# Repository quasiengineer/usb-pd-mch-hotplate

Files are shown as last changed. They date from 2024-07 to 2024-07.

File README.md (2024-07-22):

# USB-powered hot plate

Video about this project:
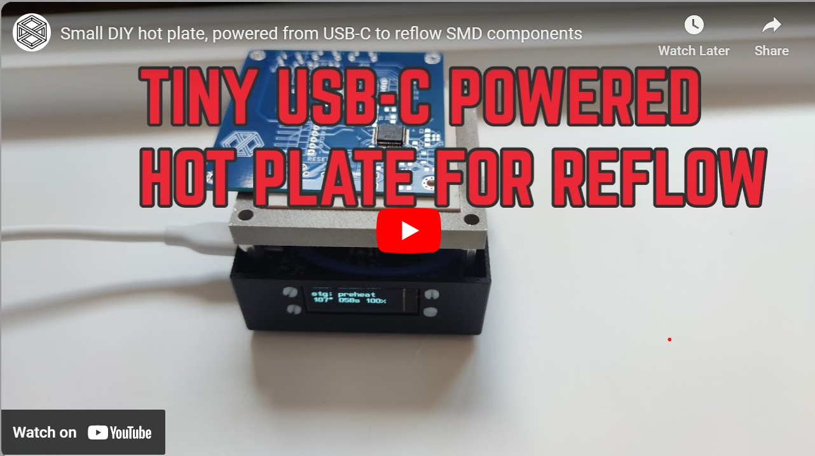
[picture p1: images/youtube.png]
Video about this project (https://www.youtube.com/watch?v=0ewrXzEZL8w)


## Board

Schematics in [pdf format](./pcb/usb-pd-mch-hotplate.pdf)

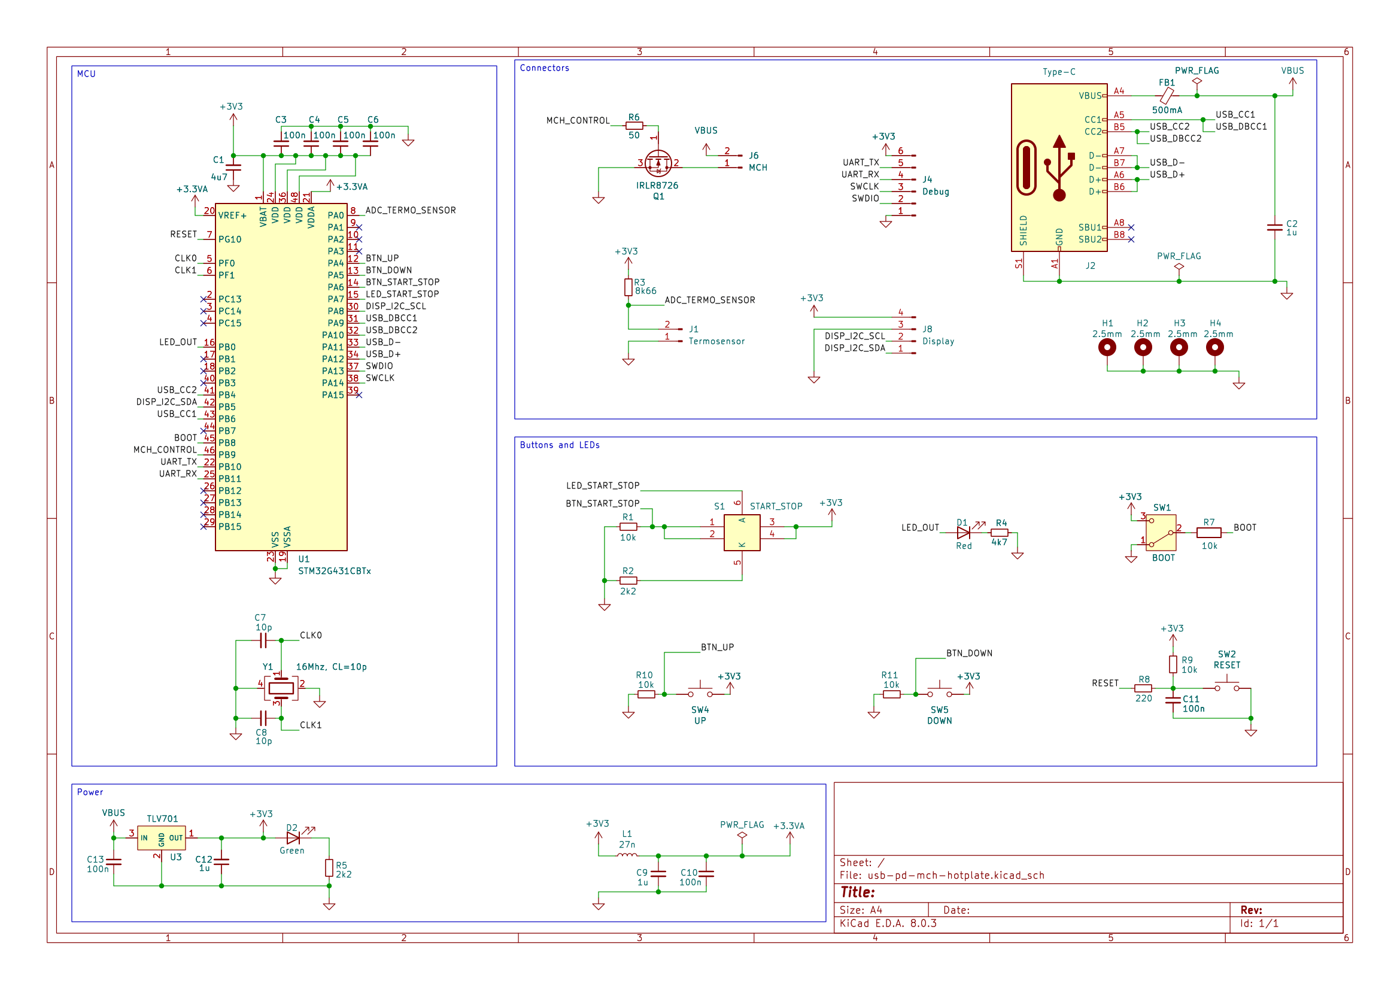
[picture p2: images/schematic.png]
schematic


Archive with gerber files and drill locations could be found [here](./pcb/manufacturing/manufacturing.zip)

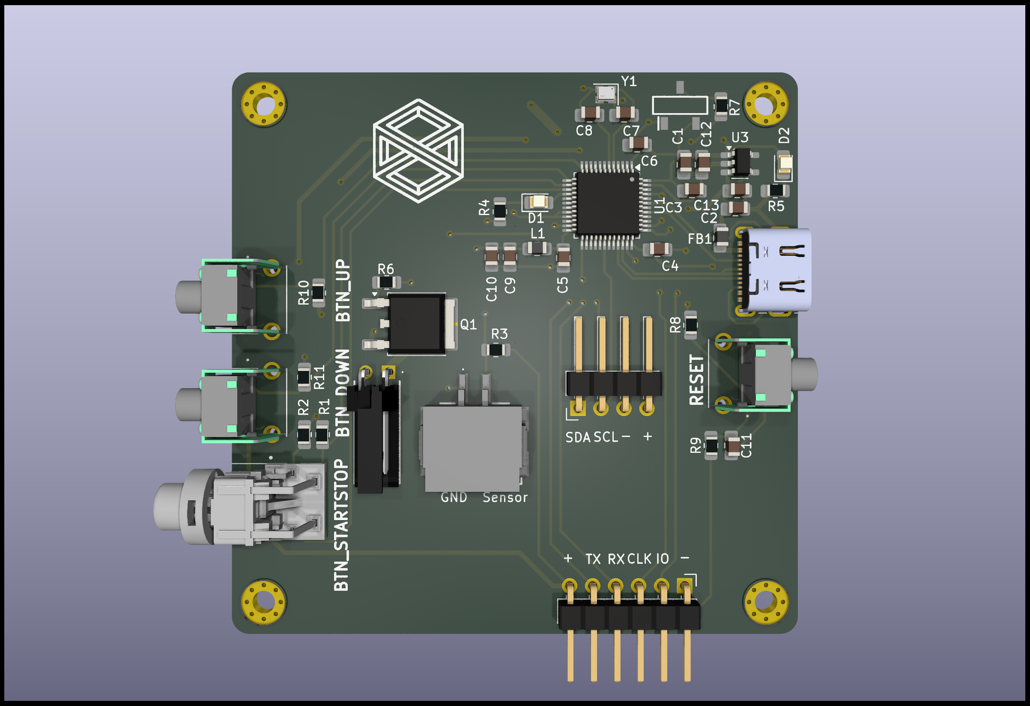
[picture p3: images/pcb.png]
pcb


Bill of material in [CSV format](./pcb/usb-pd-mch-hotplate.csv)

|Reference |Value |Mouser Part Number  |Qty|DNP|
|---|---|---|---|---|
|C1 |4u7 |187-CL21A475KPFNNNF |1  | |
|C2 |1u |187-CL21B105MBFNNNE |1  | |
|C3,C4,C5,C6,C10,C11,C13|100n |187-CL21B104KACNNND |7  | |
|C7,C8 |10p |603-CC805JRNPO9BN100|2  | |
|C9,C12 |1u |187-CL21B105KPFNNNE |2  | |
|D1 |Red |710-150080RS75000 |1  | |
|D2 |Green |710-150080GS75000 |1  | |
|FB1 |500mA |652-MH2029-301Y |1  | |
|J1 |Termosensor  |305-234832 |1  | |
|J2 |Type-C |656-DX07S016JA1R1500|1  | |
|J4 |Debug |649-1012937990604BLF|1  | |
|J6 |MCH |710-66100211722 |1  | |
|J8 |Display |649-10027011-404HLF |1  | |
|L1 |27n |652-CE201210-27NJ |1  | |
|Q1 |IRLR8726 |942-IRLR8726TRPBF |1  | |
|R1,R7,R9,R10,R11 |10k |603-RC0805FR-1010KL |5  | |
|R2,R5 |2k2 |603-RC0805FR-072K2L |2  | |
|R3 |8k66 |603-AC0805JR-073K3L |1  | |
|R4 |4k7 |603-RC0805FR-074K7P |1  | |
|R6 |50 |603-AC0805FR-07100RL|1  | |
|R8 |220 |603-RT0805FRE07220RL|1  | |
|S1 |START_STOP |612-TL1250F180GQRCLR|1  | |
|SW1 |BOOT |611-TDD01H0SB1R |1  | |
|SW2 |RESET |611-PTS645VH312 |1  | |
|SW4 |UP |611-PTS645VL582 |1  | |
|SW5 |DOWN |611-PTS645VL582 |1  | |
|U1 |STM32G431CBTx| 511-STM32G431CBT6  |1  | |
|U3 |TLV701 |595-TLV70133DBVRM3  |1  | |
|Y1 |16Mhz, CL=10p|81-XRCGB16M000FXN02R|1  | |

## Assembly

### Chassis

Step file for [board case](./chassis/PCB chassis.STEP)
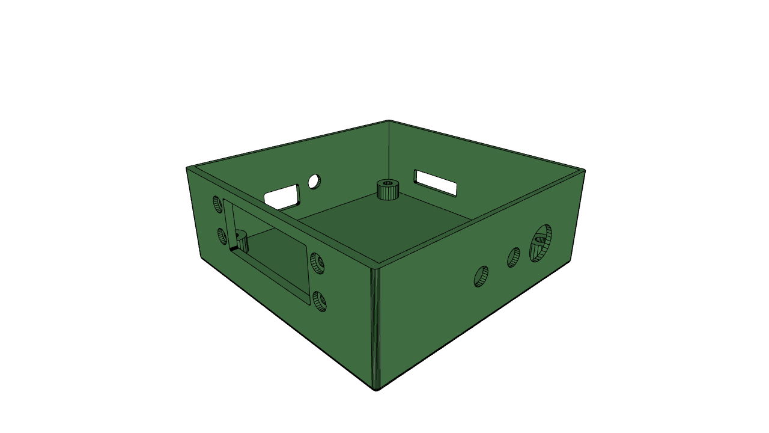
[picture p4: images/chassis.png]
chassis


Step file for [MCH holder](./chassis/MCH holder.STEP). Please note that it's better to adjust model for exact dimensions of MCH plate (plus some tolerance).
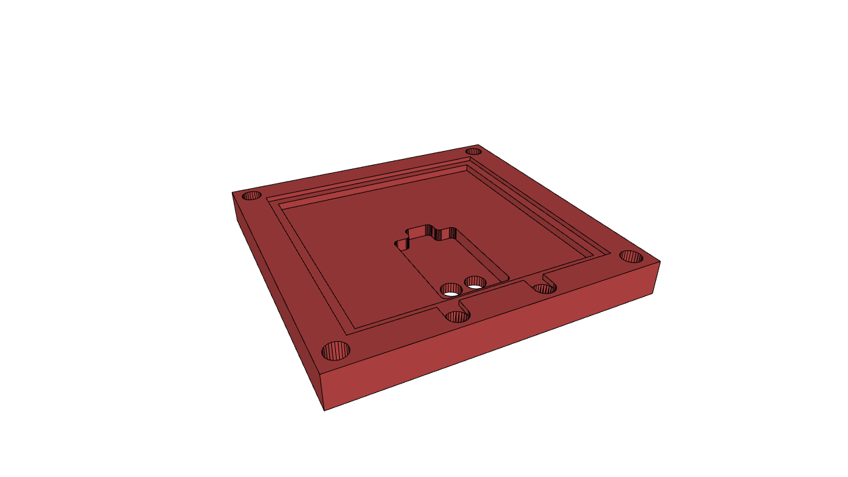
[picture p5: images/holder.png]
holder


### Hardware and extra parts

- MCH itself, 50x50x2mm, up to 24V, 150W
- steel washers, M2x5, 0.2mm thick, 8 pcs
- ceramic fiber paper
- brass inserts, M2xL4xOD3, 4 pcs
- steel standoffs, M2xL25, 4 pcs
- bolts for MCH holder mount, M2xL6xOD4, 4pcs
- NTC 100k thermistor, 	871-B57703M1104A002
- display, DFRobot DFR0647
- bolts for display mount, 144-04M020040HN, 4pcs
- nuts for display mount, 144-50M020040F004, 4pcs
- thermosensor connector, 305-364198
- thermosensor connector terminals, 305-464766 2pcs
- MCH element connector, 710-661002151922
- display connectors, 649-65039-033ELF, 2pcs
- display connector terminals, 649-47217-000LF, 8pcs
- kapton tape
- high temperature silicone sealant, K2 B205N

### Assembly steps

1. Install heat set inserts into PCB chassis
2. Place PCB inside chassis
3. Put washers from ceramic fiber paper at the mounting holes
4. Put steel washers above ceramic fiber paper washers
5. Screw standoffs to chassis mounting holes
6. Install display to the display slot by using 4 bolts and 4 nuts
7. Connect display to the board by using 4-pin cable
8. Glue thermo sensor to the MCH element
9. Better isolate MCH wires to avoid electrical contact with MCH holder
10. Place MCH plate into MCH holder and route wires from thermo sensor and MCH element itself through corresponding holes
11. Crimp connectors to thermo sensor and MCH element wires
12. Connect thermo sensor and MCH element to the female connectors on the board
13. Put steel washers to the upper part of standoffs 
14. Put washers from ceramic fiber paper above steel washers
15. Place MCH holder to standoffs and screw it

## Firmware

There is compiled [hex file](./firmware/bin/usb-pd-mch-hotplate.hex) in repository, that could be flashed to PCB.

Make sure that `BOOT` switch lever shifted in direction of logo and connect the board via USB and use stm32 programming software. I am using stm32programmer.

## Software

Make sure that `BOOT` switch lever shifted in direction to near board edge and connect the board via USB to USB PD 3.0 compatible power supply that can output at least 100W of power. 

Green LED should be lighting and red LED should be flashing.

Display should show initial menu with the list of programs.

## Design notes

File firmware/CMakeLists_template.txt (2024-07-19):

#${templateWarning}
set(CMAKE_SYSTEM_NAME Generic)
set(CMAKE_SYSTEM_VERSION 1)
${cmakeRequiredVersion}
# specify cross-compilers and tools
set(CMAKE_C_COMPILER arm-none-eabi-gcc)
set(CMAKE_CXX_COMPILER arm-none-eabi-g++)
set(CMAKE_ASM_COMPILER  arm-none-eabi-gcc)
set(CMAKE_AR arm-none-eabi-ar)
set(CMAKE_OBJCOPY arm-none-eabi-objcopy)
set(CMAKE_OBJDUMP arm-none-eabi-objdump)
set(SIZE arm-none-eabi-size)
set(CMAKE_TRY_COMPILE_TARGET_TYPE STATIC_LIBRARY)

# project settings
project(${projectName} C CXX ASM)
set(CMAKE_CXX_STANDARD 17)
set(CMAKE_C_STANDARD 11)

#Uncomment for hardware floating point
#add_compile_definitions(ARM_MATH_CM4;ARM_MATH_MATRIX_CHECK;ARM_MATH_ROUNDING)
#add_compile_options(-mfloat-abi=hard -mfpu=fpv4-sp-d16)
#add_link_options(-mfloat-abi=hard -mfpu=fpv4-sp-d16)

#Uncomment for software floating point
#add_compile_options(-mfloat-abi=soft)

add_compile_options(-mcpu=${mcpu} -mthumb -mthumb-interwork)
add_compile_options(-ffunction-sections -fdata-sections -fno-common -fmessage-length=0)

# uncomment to mitigate c++17 absolute addresses warnings
#set(CMAKE_CXX_FLAGS "$${CMAKE_CXX_FLAGS} -Wno-register")

# Enable assembler files preprocessing
add_compile_options($<$<COMPILE_LANGUAGE:ASM>:-x$<SEMICOLON>assembler-with-cpp>)

if ("$${CMAKE_BUILD_TYPE}" STREQUAL "Release")
    message(STATUS "Maximum optimization for speed")
    add_compile_options(-Ofast)
elseif ("$${CMAKE_BUILD_TYPE}" STREQUAL "RelWithDebInfo")
    message(STATUS "Maximum optimization for speed, debug info included")
    add_compile_options(-Ofast -g)
elseif ("$${CMAKE_BUILD_TYPE}" STREQUAL "MinSizeRel")
    message(STATUS "Maximum optimization for size")
    add_compile_options(-Os)
else ()
    message(STATUS "Minimal optimization, debug info included")
    add_compile_options(-Og -g)
endif ()

include_directories(${includes} App App/modules)

add_definitions(${defines})

file(GLOB_RECURSE SOURCES ${sources} "App/*.*")

set(LINKER_SCRIPT $${CMAKE_SOURCE_DIR}/${linkerScript})

add_link_options(-Wl,-gc-sections,--print-memory-usage,-Map=$${PROJECT_BINARY_DIR}/$${PROJECT_NAME}.map)
add_link_options(-mcpu=${mcpu} -mthumb -mthumb-interwork)
add_link_options(-T $${LINKER_SCRIPT})

add_executable($${PROJECT_NAME}.elf $${SOURCES} $${LINKER_SCRIPT})

set(HEX_FILE $${PROJECT_BINARY_DIR}/$${PROJECT_NAME}.hex)
set(BIN_FILE $${PROJECT_BINARY_DIR}/$${PROJECT_NAME}.bin)

add_custom_command(TARGET $${PROJECT_NAME}.elf POST_BUILD
        COMMAND $${CMAKE_OBJCOPY} -Oihex $<TARGET_FILE:$${PROJECT_NAME}.elf> $${HEX_FILE}
        COMMAND $${CMAKE_OBJCOPY} -Obinary $<TARGET_FILE:$${PROJECT_NAME}.elf> $${BIN_FILE}
        COMMENT "Building $${HEX_FILE}
Building $${BIN_FILE}")

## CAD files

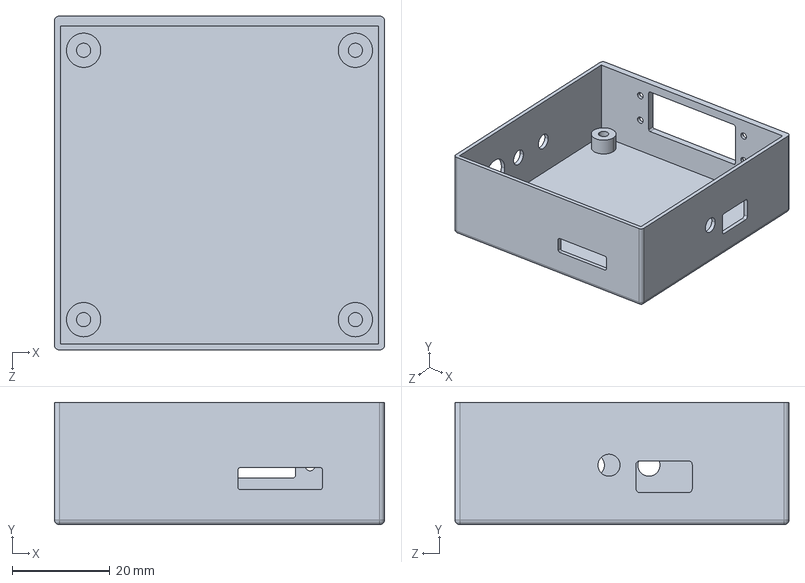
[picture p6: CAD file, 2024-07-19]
chassis/PCB chassis.STEP
67.4 x 25.0 x 68.2 mm

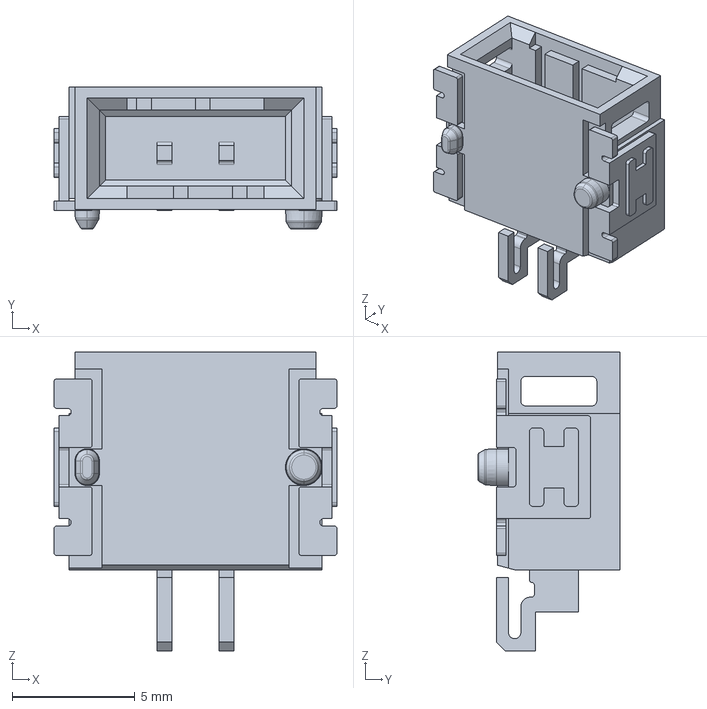
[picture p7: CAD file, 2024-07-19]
pcb/components/3d/c-234832-e-1-3d.stp
11.5 x 5.80 x 12.2 mm

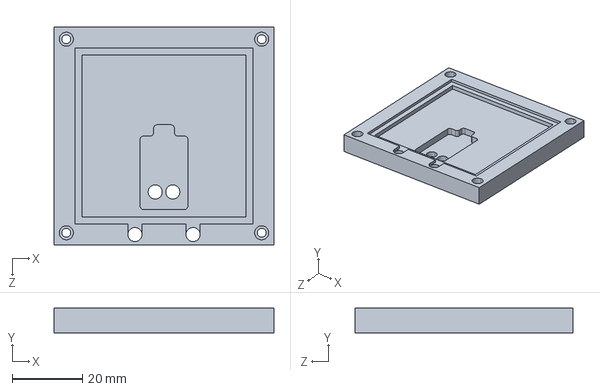
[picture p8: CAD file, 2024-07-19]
chassis/MCH holder.STEP
62.5 x 7.00 x 62.0 mm

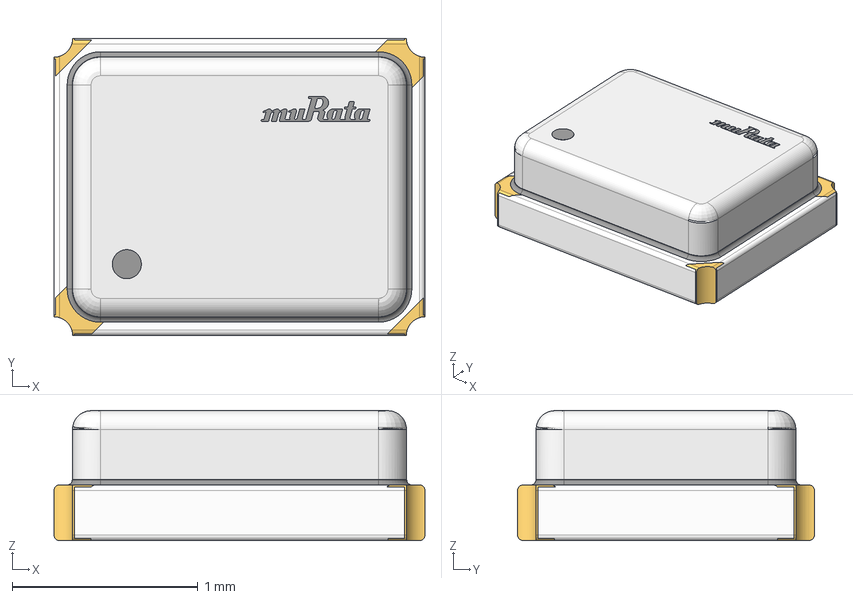
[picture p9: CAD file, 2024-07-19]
pcb/components/3d/XRCGB16M000FXN02R0.stp
2.00 x 1.60 x 0.702 mm

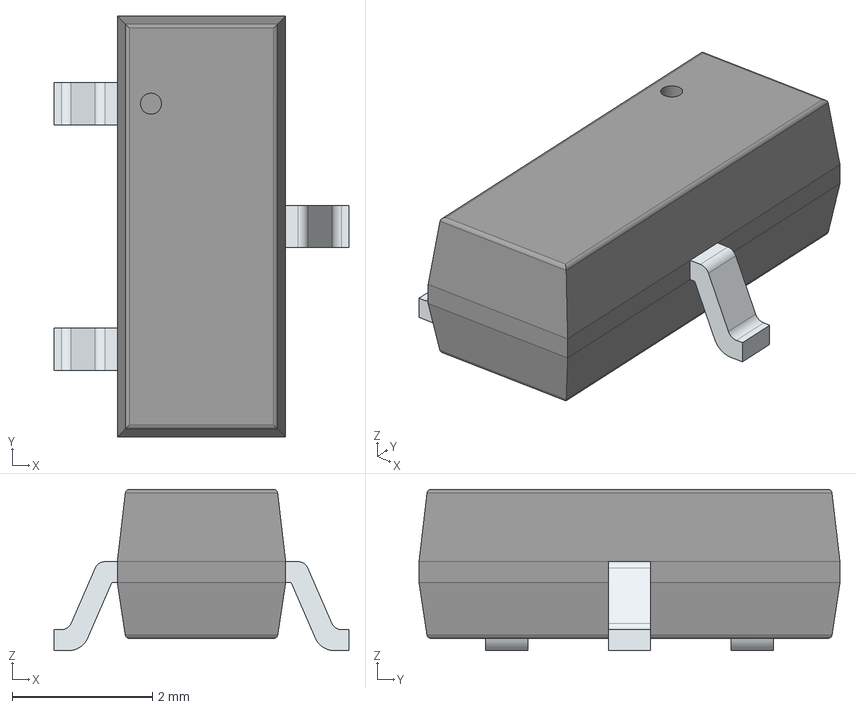
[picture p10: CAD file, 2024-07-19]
pcb/components/3d/TDD01H0SB1R.stp
4.20 x 6.00 x 2.30 mm
PinsArrayL
FilletPinR

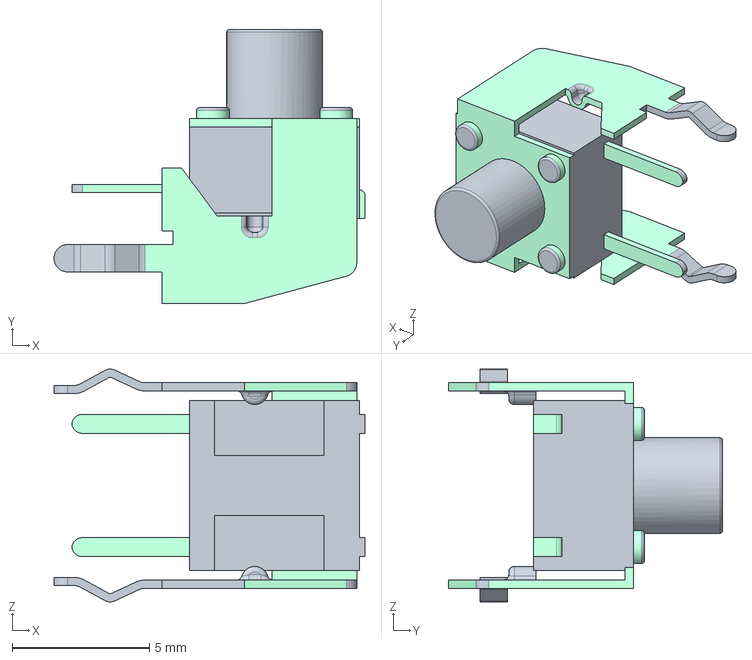
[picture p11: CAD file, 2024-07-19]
pcb/components/3d/PTS645VL58-2LFS.stp
11.4 x 10.0 x 8.50 mm

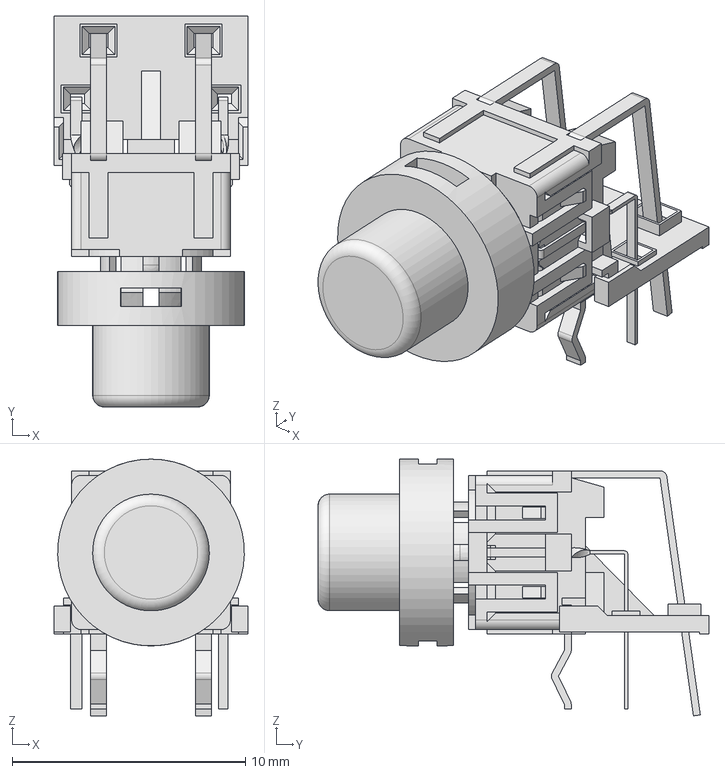
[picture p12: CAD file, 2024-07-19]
pcb/components/3d/TL1250F180GQRCLR.stp
8.30 x 16.8 x 11.0 mm

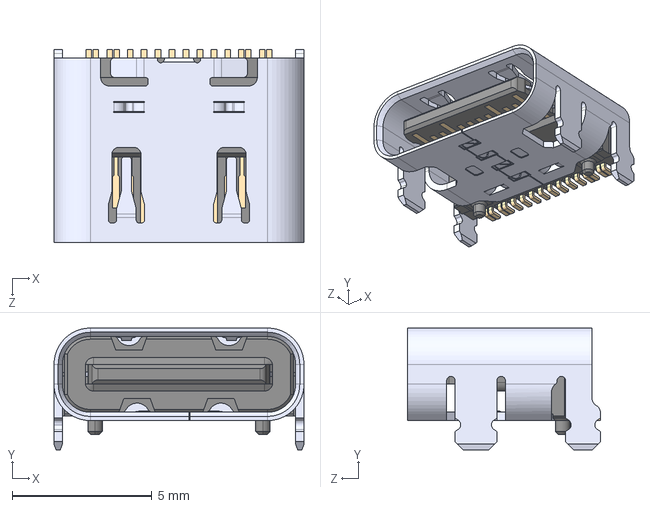
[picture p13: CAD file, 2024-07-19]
pcb/components/3d/DX07S016JA1R1500.stp
8.94 x 4.36 x 6.90 mm

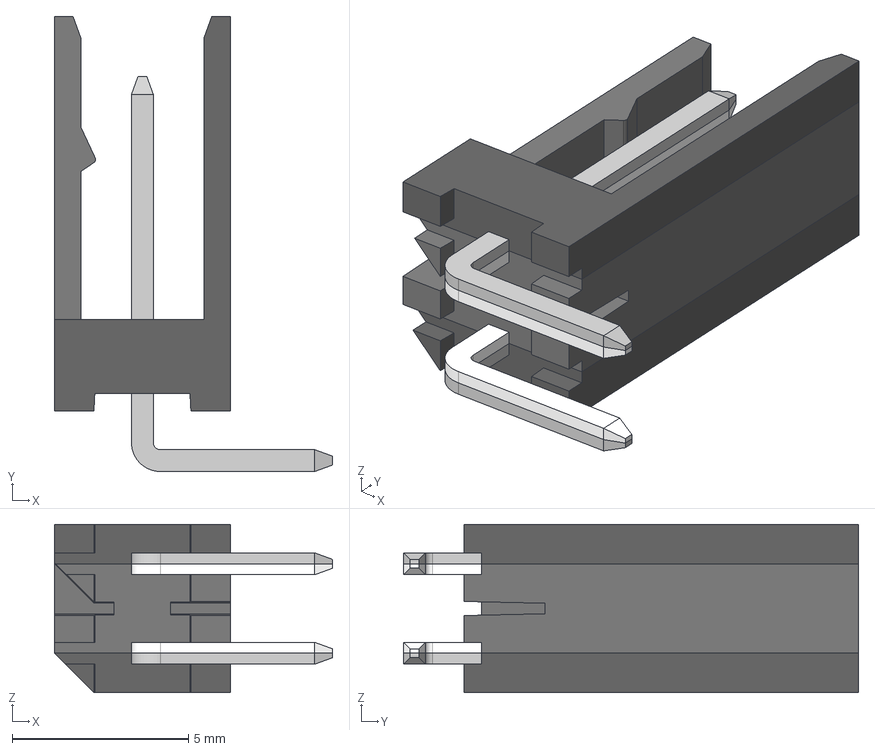
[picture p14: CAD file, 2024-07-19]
pcb/components/3d/66100211722 (rev1).stp
7.90 x 12.9 x 4.78 mm
6610xx11722_02_06_DX
6610xx11722_02_06_SX

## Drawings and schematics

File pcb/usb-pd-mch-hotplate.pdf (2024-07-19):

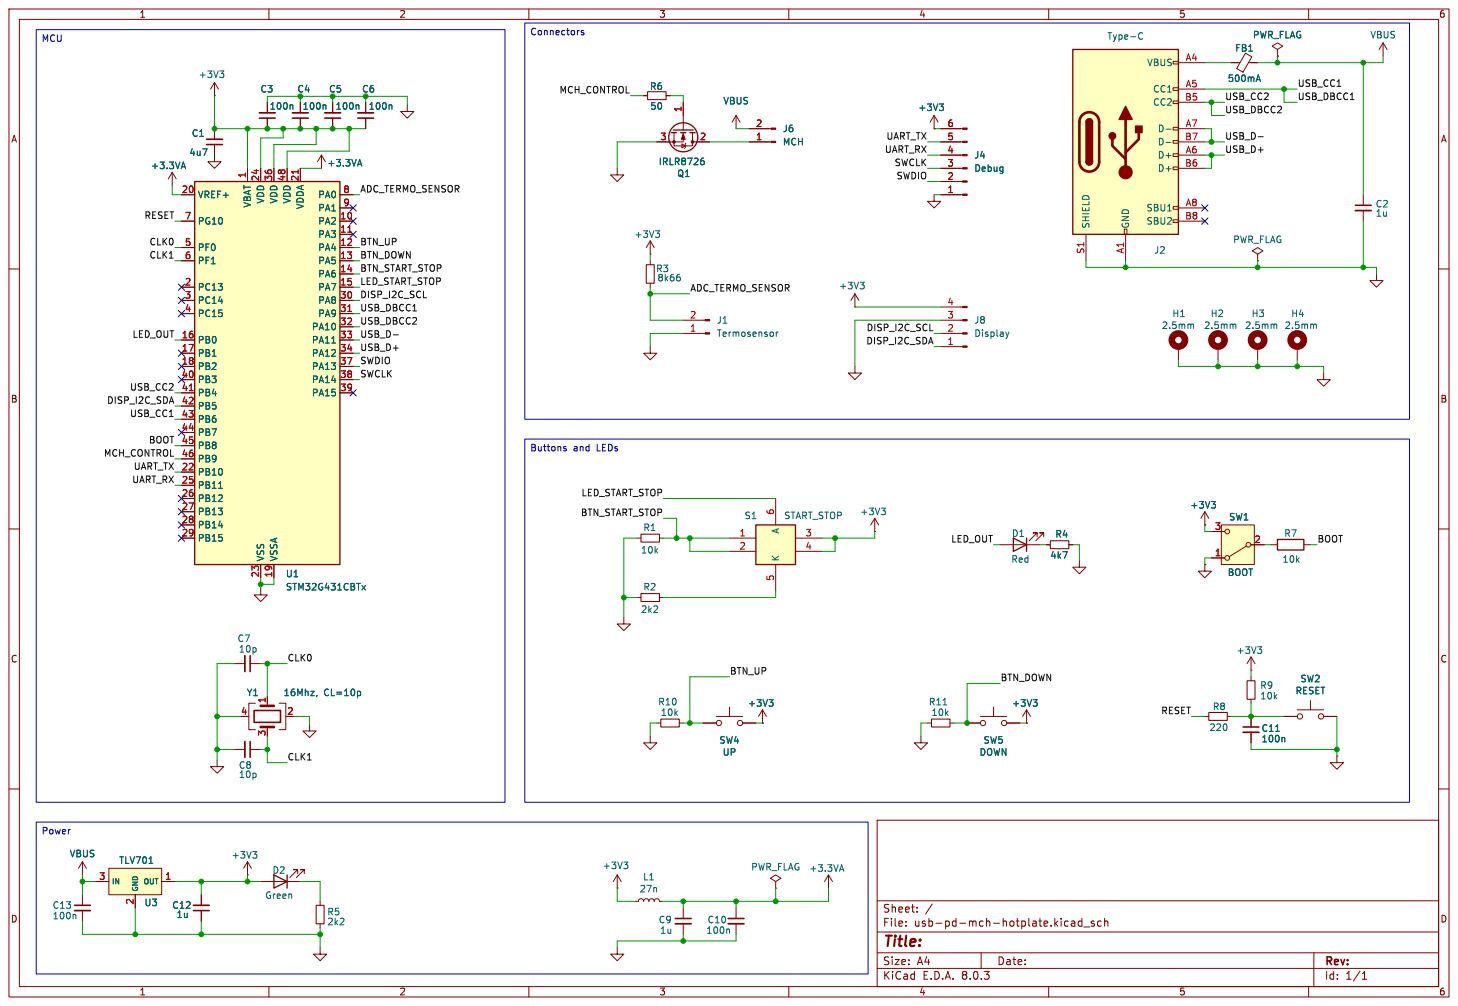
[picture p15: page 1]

1 PA2 10 PA3 11 PA4 12 PA5 13 PA6 14 PA7 15 PB0 16 PB1 17 PB2 18 VSSA 19 PC13 2 VREF+ 20 VDDA 21 PB10 22 VSS 23 VDD 24 PB11 25 PB12 26 PB13 27 PB14 28 PB15 29 PC14 3 PA8 30 PA9 31 PA10 32 PA11 33 PA12 34 VDD 36 PA13 37 PA14 38 PA15 39 PC15 4 PB3 40 PB4 41 PB5 42 PB6 43 PB7 44 PB8 45 PB9 46 VDD 48 PF0 5 PF1 6 PG10 7 PA0 8 PA1 9 U1STM32G431CBTx

1 PA2 10 PA3 11 PA4 12 PA5 13 PA6 14 PA7 15 PB0 16 PB1 17 PB2 18 VSSA 19 PC13 2 VREF+ 20 VDDA 21 PB10 22 VSS 23 VDD 24 PB11 25 PB12 26 PB13 27 PB14 28 PB15 29 PC14 3 PA8 30 PA9 31 PA10 32 PA11 33 PA12 34 VDD 36 PA13 37 PA14 38 PA15 39 PC15 4 PB3 40 PB4 41 PB5 42 PB6 43 PB7 44 PB8 45 PB9 46 VDD 48 PF0 5 PF1 6 PG10 7 PA0 8 PA1 9 Y1 16Mhz, CL=10p

Id: 1/1 Title: File: usb-pd-mch-hotplate.kicad_sch Sheet: / R1

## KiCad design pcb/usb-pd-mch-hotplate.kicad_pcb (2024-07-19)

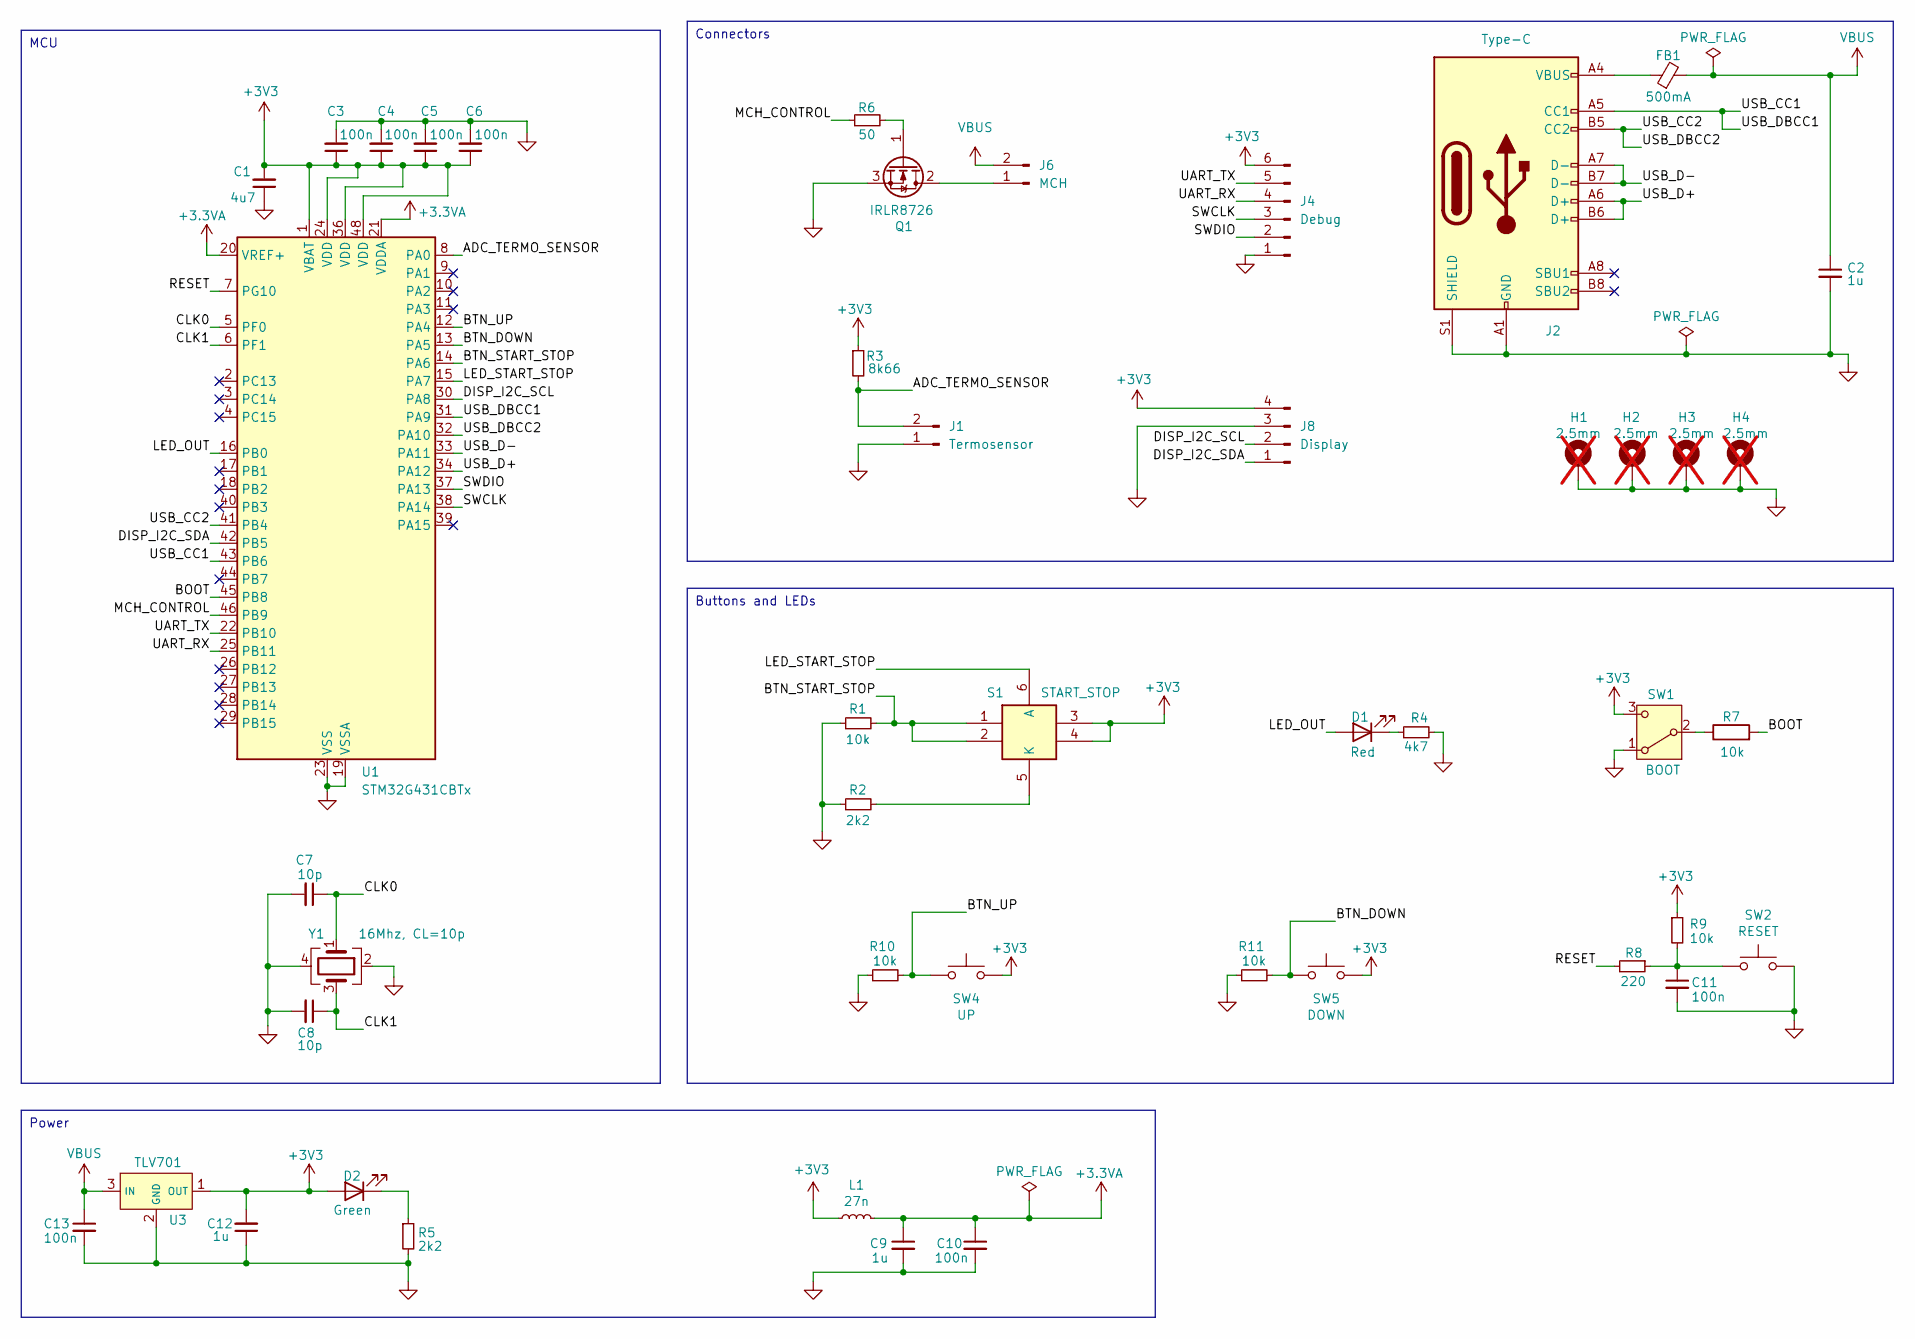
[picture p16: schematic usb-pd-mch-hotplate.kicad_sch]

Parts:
C1: 4u7; C_0805_2012Metric_Pad1.18x1.45mm_HandSolder; Mouser Part Number 187-CL21A475KPFNNNF
C2: 1u; C_0805_2012Metric_Pad1.18x1.45mm_HandSolder; Mouser Part Number 187-CL21B105MBFNNNE
C3, C4, C5, C6, C10, C11, C13: 100n; C_0805_2012Metric_Pad1.18x1.45mm_HandSolder; Mouser Part Number 187-CL21B104KACNNND
C7, C8: 10p; C_0805_2012Metric_Pad1.18x1.45mm_HandSolder; Mouser Part Number 603-CC805JRNPO9BN100
C9, C12: 1u; C_0805_2012Metric_Pad1.18x1.45mm_HandSolder; Mouser Part Number 187-CL21B105KPFNNNE
D1: Red; LED_0805_2012Metric_Pad1.15x1.40mm_HandSolder; Mouser Part Number 710-150080RS75000
D2: Green; LED_0805_2012Metric_Pad1.15x1.40mm_HandSolder; Mouser Part Number 710-150080GS75000
FB1: 500mA; L_0805_2012Metric_Pad1.15x1.40mm_HandSolder; Mouser Part Number 652-MH2029-301Y
H1, H2, H3, H4: 2.5mm; MountingHole_2.5mm_Pad_Via; not fitted
J1: Termosensor; 234832E; Mouser Part Number 305-234832
J2: Type-C; USB_C_Receptacle_JAE_DX07S016JA1R1500; Mouser Part Number 656-DX07S016JA1R1500
J4: Debug; PinHeader_1x06_P2.54mm_Horizontal; Mouser Part Number 649-1012937990604BLF
J6: MCH; Conn_66100211722; Mouser Part Number 710-66100211722
J8: Display; PinHeader_1x04_P2.54mm_Horizontal; Mouser Part Number 649-10027011-404HLF
L1: 27n; L_0805_2012Metric_Pad1.15x1.40mm_HandSolder; Mouser Part Number 652-CE201210-27NJ
Q1: IRLR8726; TO-252-2; Mouser Part Number 942-IRLR8726TRPBF
R1, R7, R9, R10, R11: 10k; R_0805_2012Metric_Pad1.20x1.40mm_HandSolder; Mouser Part Number 603-RC0805FR-1010KL
R2, R5: 2k2; R_0805_2012Metric_Pad1.20x1.40mm_HandSolder; Mouser Part Number 603-RC0805FR-072K2L
R3: 8k66; R_0805_2012Metric_Pad1.20x1.40mm_HandSolder; Mouser Part Number 603-AC0805JR-073K3L
R4: 4k7; R_0805_2012Metric_Pad1.20x1.40mm_HandSolder; Mouser Part Number 603-RC0805FR-074K7P
R6: 50; R_0805_2012Metric_Pad1.20x1.40mm_HandSolder; Mouser Part Number 603-AC0805FR-07100RL
R8: 220; R_0805_2012Metric_Pad1.20x1.40mm_HandSolder; Mouser Part Number 603-RT0805FRE07220RL
S1: START_STOP; TL1250F180GQRCLR; Mouser Part Number 612-TL1250F180GQRCLR
SW1: BOOT; SOT175P420X230-3N; Mouser Part Number 611-TDD01H0SB1R
SW2: RESET; PTS645VL582LFS; Mouser Part Number 611-PTS645VH312
SW4: UP; PTS645VL582LFS; Mouser Part Number 611-PTS645VL582
SW5: DOWN; PTS645VL582LFS; Mouser Part Number 611-PTS645VL582
U1: STM32G431CBTx; LQFP-48_7x7mm_P0.5mm; Mouser Part Number 511-STM32G431CBT6
U3: TLV701; SOT-23-5_HandSoldering; Mouser Part Number 595-TLV70133DBVRM3
Y1: 16Mhz, CL=10p; Crystal_SMD_2016-4Pin_2.0x1.6mm; Mouser Part Number 81-XRCGB16M000FXN02R

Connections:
+3.3VA: C9.1, C10.1, L1.2, U1.20 (VREF+), U1.21 (VDDA)
+3V3: C1.2, C3.1, C4.1, C5.1, C6.1, C12.2, D2.2 (A), J4.6, J8.4, L1.1, R3.1, R9.1, SW1.3 (C), U1.1 (VBAT), U1.24 (VDD), U1.36 (VDD), U1.48 (VDD), U3.1 (OUT); also elsewhere on the board
/ADC_TERMO_SENSOR: J1.2, R3.2, U1.8 (PA0)
/BOOT: R7.2, U1.45 (PB8)
/BTN_DOWN: R11.2, U1.13 (PA5); also elsewhere on the board
/BTN_START_STOP: R1.2, S1.1, S1.2, U1.14 (PA6); also elsewhere on the board
/BTN_UP: R10.2, U1.12 (PA4); also elsewhere on the board
/CLK0: C7.1, U1.5 (PF0), Y1.1
/CLK1: C8.1, U1.6 (PF1), Y1.3
/DISP_I2C_SCL: J8.2, U1.30 (PA8)
/DISP_I2C_SDA: J8.1, U1.42 (PB5)
/LED_OUT: D1.2 (A), U1.16 (PB0)
/LED_START_STOP: S1.6 (A), U1.15 (PA7); also elsewhere on the board
/MCH_CONTROL: R6.1, U1.46 (PB9)
/RESET: R8.2, U1.7 (PG10)
/SWCLK: J4.3, U1.38 (PA14)
/SWDIO: J4.2, U1.37 (PA13)
/UART_RX: J4.4, U1.25 (PB11)
/UART_TX: J4.5, U1.22 (PB10)
/USB_CC1: J2.A5 (CC1), U1.31 (PA9), U1.43 (PB6)
/USB_CC2: J2.B5 (CC2), U1.32 (PA10), U1.41 (PB4)
/USB_D+: J2.A6 (D+), J2.B6 (D+), U1.34 (PA12)
/USB_D-: J2.A7 (D-), J2.B7 (D-), U1.33 (PA11)
GND: C1.1, C2.2, C3.2, C4.2, C5.2, C6.2, C7.2, C8.2, C9.2, C10.2, C11.2, C12.1, C13.2, H1.1, H2.1, H3.1, H4.1, J1.1, J2.A1 (GND), J2.A12 (GND), J2.B1 (GND), J2.B12 (GND), J2.S1 (SHIELD), J4.1, J8.3, Q1.3 (S), R1.1, R2.1, R4.2, R5.2, R10.1, R11.1, SW1.1 (A), U1.19 (VSSA), U1.23 (VSS), U1.35 (VSS), U1.47 (VSS), U3.2 (GND), Y1.2, Y1.4; also elsewhere on the board
unnamed 24: C11.1, R8.1, R9.2, SW2.1; also elsewhere on the board
unnamed: D1.1 (K), R4.1
unnamed: D2.1 (K), R5.1
unnamed: FB1.1, J2.A4 (VBUS), J2.A9 (VBUS), J2.B4 (VBUS), J2.B9 (VBUS)
unnamed: J6.1, Q1.2 (D)
unnamed: Q1.1 (G), R6.2
unnamed 30: R2.2, S1.5 (K); also elsewhere on the board
unnamed: R7.1, SW1.2 (B)
VBUS: C2.1, C13.1, FB1.2, J6.2, U3.3 (IN)

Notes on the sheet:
Buttons and LEDs
Power
MCU
Connectors

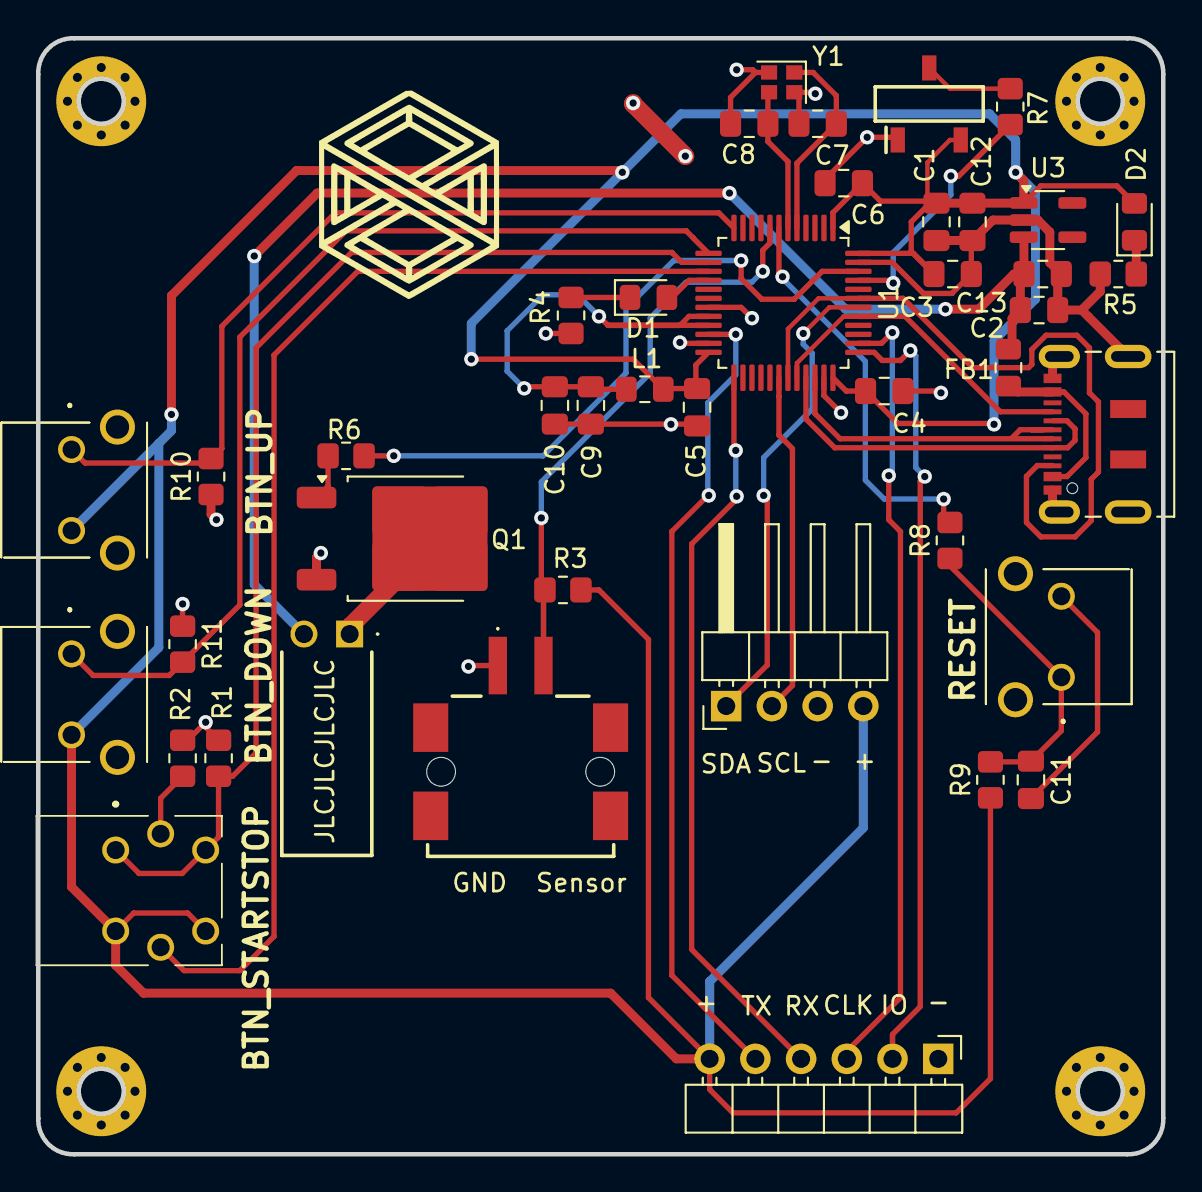
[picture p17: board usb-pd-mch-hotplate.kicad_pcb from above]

Board: 2 copper layers, 62.5 x 62.0 mm, 46 parts (0 on the bottom side), 33 nets.

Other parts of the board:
BTN_DOWN: DOWN; PTS645VL582LFS
BTN_STARTSTOP: START_STOP; TL1250F180GQRCLR
BTN_UP: UP; PTS645VL582LFS
RESET: RESET; PTS645VL582LFS

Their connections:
+3V3: BTN_DOWN.2, BTN_STARTSTOP.3, BTN_STARTSTOP.4, BTN_UP.2; also elsewhere on the board
/BTN_DOWN: BTN_DOWN.1; also elsewhere on the board
/BTN_START_STOP: BTN_STARTSTOP.1, BTN_STARTSTOP.2; also elsewhere on the board
/BTN_UP: BTN_UP.1; also elsewhere on the board
/LED_START_STOP: BTN_STARTSTOP.6 (A); also elsewhere on the board
GND: RESET.2; also elsewhere on the board
unnamed 24: RESET.1; also elsewhere on the board
unnamed 30: BTN_STARTSTOP.5 (K); also elsewhere on the board

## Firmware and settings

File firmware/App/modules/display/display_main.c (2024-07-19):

#include "display.h"
#include "display_ssd1306.h"

void display_init() {
  ssd1306_Init(&hi2c3);
}

void display_redraw(char * firstLine, char * secondLine) {
  ssd1306_PutString(firstLine, 0, 0, 1);
  ssd1306_PutString(secondLine, 0, 1, 1);
  ssd1306_UpdateScreen(&hi2c3);
}

void display_draw(char * str, uint8_t x, uint8_t y, uint8_t updateScreen) {
  ssd1306_PutString(str, x, y, 0);
  if (updateScreen) {
    ssd1306_UpdateScreen(&hi2c3);
  }
}

void display_clear(uint8_t updateScreen) {
  ssd1306_Clear();

  if (updateScreen) {
    ssd1306_UpdateScreen(&hi2c3);
  }
}

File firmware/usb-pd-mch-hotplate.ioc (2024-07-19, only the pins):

Mcu.UserName=STM32G431CBTx
PA0.GPIO_Label=ADC_TERMO_SENSOR
PA0.Signal=ADC1_IN1
PA10.Signal=UCPD1_DBCC2
PA13.Signal=SYS_JTMS-SWDIO
PA14.Signal=SYS_JTCK-SWCLK
PA4.GPIO_Label=BTN_UP
PA4.Signal=GPIO_Input
PA5.GPIO_Label=BTN_DOWN
PA5.Signal=GPIO_Input
PA6.GPIO_Label=BTN_START_STOP
PA6.Signal=GPIO_Input
PA7.GPIO_Label=LED_START_STOP
PA7.Signal=GPIO_Output
PA8.GPIO_Label=DISP_I2C_SCL
PA8.Signal=I2C3_SCL
PA9.Signal=UCPD1_DBCC1
PB0.GPIO_Label=LED_OUT
PB0.Signal=GPIO_Output
PB10.Signal=USART3_TX
PB11.Signal=USART3_RX
PB3.Signal=SYS_JTDO-SWO
PB4.Signal=UCPD1_CC2
PB5.GPIO_Label=DISP_I2C_SDA
PB5.Signal=I2C3_SDA
PB6.Signal=UCPD1_CC1
PB9.GPIO_Label=MCH_CONTROL
PB9.Signal=S_TIM4_CH4
PF0-OSC_IN.Signal=RCC_OSC_IN
PF1-OSC_OUT.Signal=RCC_OSC_OUT

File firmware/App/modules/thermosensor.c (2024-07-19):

#include "main.h"
#include "thermosensor.h"

static uint16_t adcTable[][2] = {
  { 99, 254 },
  { 100, 253 },
  { 102, 252 },
  { 103, 251 },
  { 105, 250 },
  { 106, 249 },
  { 108, 248 },
  { 110, 247 },
  { 112, 246 },
  { 114, 245 },
  { 116, 244 },
  { 117, 243 },
  { 119, 242 },
  { 121, 241 },
  { 123, 240 },
  { 125, 239 },
  { 128, 238 },
  { 130, 237 },
  { 132, 236 },
  { 134, 235 },
  { 136, 234 },
  { 138, 233 },
  { 141, 232 },
  { 143, 231 },
  { 146, 230 },
  { 148, 229 },
  { 151, 228 },
  { 153, 227 },
  { 156, 226 },
  { 159, 225 },
  { 162, 224 },
  { 164, 223 },
  { 167, 222 },
  { 170, 221 },
  { 173, 220 },
  { 176, 219 },
  { 179, 218 },
  { 182, 217 },
  { 185, 216 },
  { 189, 215 },
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
};

uint8_t getPlateTemperature() {
  HAL_ADC_PollForConversion(&hadc1, HAL_MAX_DELAY);
  uint32_t adcValue = HAL_ADC_GetValue(&hadc1);

  for (uint8_t i = 0; i < sizeof(adcTable) / sizeof(adcTable[0]); ++i) {
    if (adcValue < adcTable[i][0]) {
      return adcTable[i][1];
    }
  }

  return INCORRECT_TEMP_READING;
}

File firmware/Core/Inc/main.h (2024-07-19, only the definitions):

#define VDDA_APPLI 3300
#define ADC_TERMO_SENSOR_Pin GPIO_PIN_0
#define ADC_TERMO_SENSOR_GPIO_Port GPIOA
#define BTN_UP_Pin GPIO_PIN_4
#define BTN_UP_GPIO_Port GPIOA
#define BTN_DOWN_Pin GPIO_PIN_5
#define BTN_DOWN_GPIO_Port GPIOA
#define BTN_START_STOP_Pin GPIO_PIN_6
#define BTN_START_STOP_GPIO_Port GPIOA
#define LED_START_STOP_Pin GPIO_PIN_7
#define LED_START_STOP_GPIO_Port GPIOA
#define LED_OUT_Pin GPIO_PIN_0
#define LED_OUT_GPIO_Port GPIOB
#define DISP_I2C_SCL_Pin GPIO_PIN_8
#define DISP_I2C_SCL_GPIO_Port GPIOA
#define DISP_I2C_SDA_Pin GPIO_PIN_5
#define DISP_I2C_SDA_GPIO_Port GPIOB
#define MCH_CONTROL_Pin GPIO_PIN_9
#define MCH_CONTROL_GPIO_Port GPIOB

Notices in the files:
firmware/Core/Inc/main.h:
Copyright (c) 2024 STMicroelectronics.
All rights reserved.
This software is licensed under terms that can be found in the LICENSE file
